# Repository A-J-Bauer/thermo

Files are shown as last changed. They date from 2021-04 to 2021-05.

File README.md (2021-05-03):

# thermo
A simple DIY thermometer and PWA app.

This is a little fun project using cheap components to build a thermometer that can be connected to a smart phone's or computer's USB interface.

Installable PWA (Chrome only) here: https://a-j-bauer.github.io/thermo/

For phones you need an OTG USB cable.

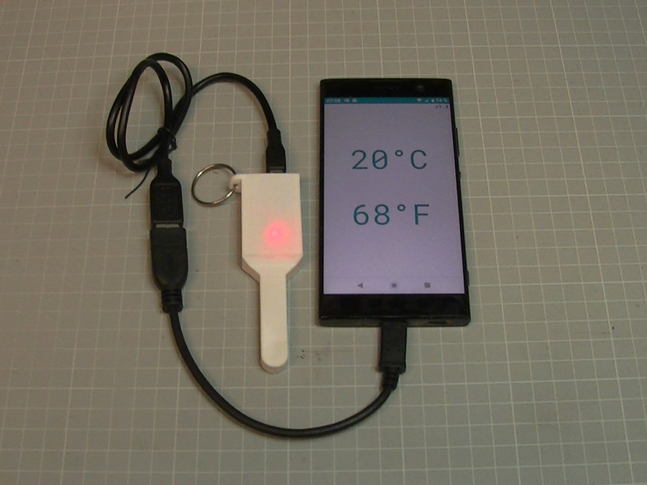
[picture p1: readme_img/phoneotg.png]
phone with otg cable


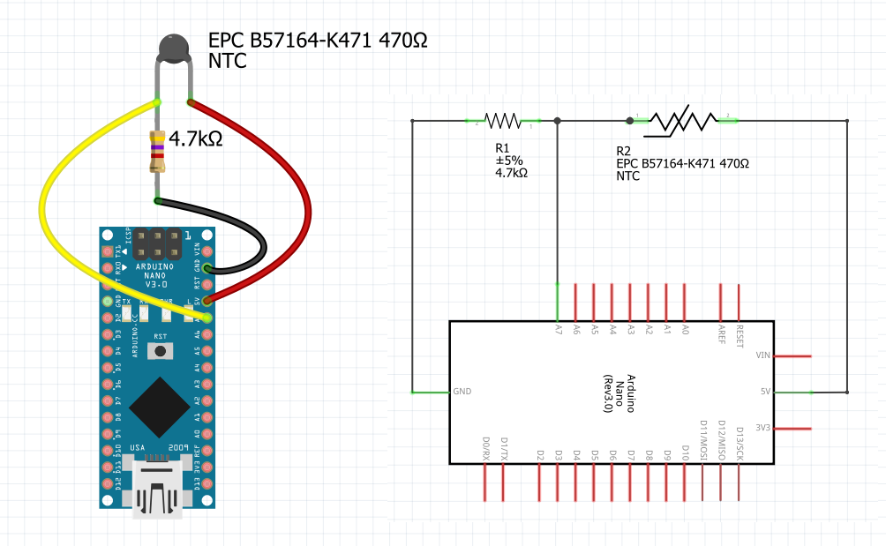
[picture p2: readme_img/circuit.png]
circuit


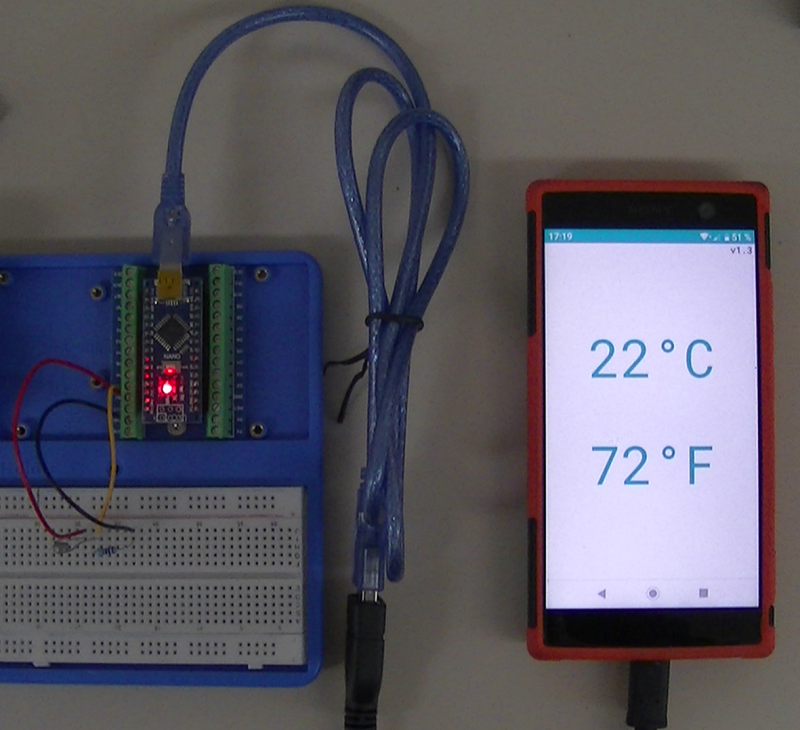
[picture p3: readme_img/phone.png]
phone


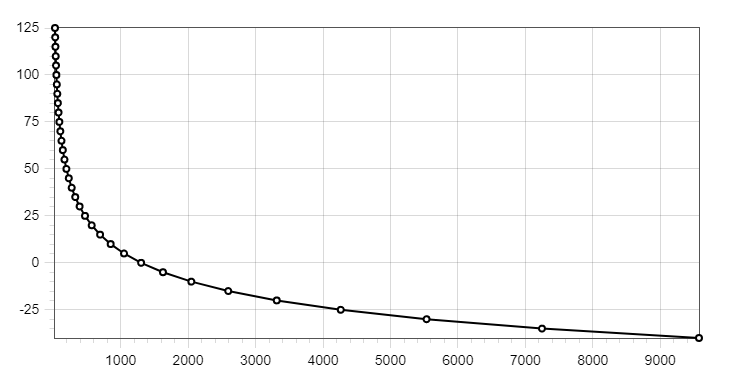
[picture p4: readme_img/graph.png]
graph


**Circuit Notes:**

The circuit is a simple voltage divider where one of the resistors is a negative temperature coefficient (NTC) thermistor, meaning it's resistance will get lower as it's temperature gets higher. At 25°C the resistance of the NTC used here is 470Ω. To avoid self heating the current flowing through the thermistor is limited by the second resistor. I picked 4.7kΩ. Knowing that the resistance is measured in terms of voltage drop accross the NTC at a certain resolution (Nano 10bits, 1024 steps for 5V, 4.9 mV/step) and looking at the data graph leads to the conclusion that the accuracy will degrade as the temperature rises.
More info: [Wikipedia Thermistor](https://en.wikipedia.org/wiki/Thermistor)

**Sensor Placement**

The Arduino itself creates heat so the NTCs position and wire length should be chosen accoringly.

The first design picked up the heat from the Microcontroller:

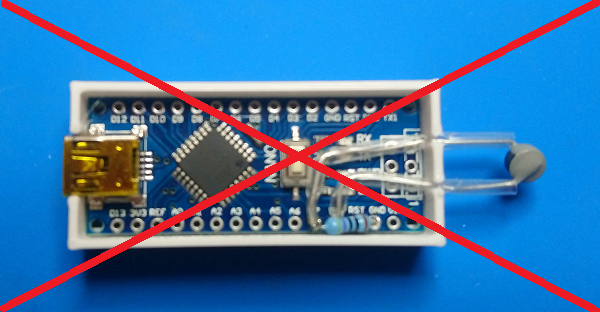
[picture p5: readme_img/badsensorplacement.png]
bad sensor placement


The second design decouples from the Arduino's heat much better:

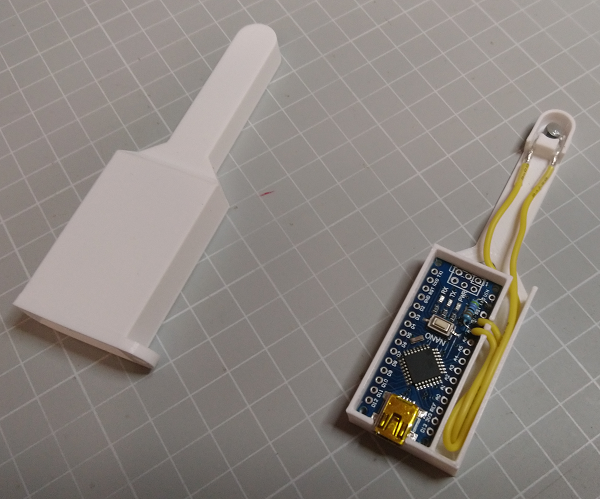
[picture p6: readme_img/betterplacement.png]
better placement


Note: The pocket where the NTC is seated in is filled up with glue a little over the brim now so that the heat from outside transfers to the NTC a little bit better/faster.

**Source Note:**
The serial.js is a modified version of Google's Serial Polyfill from here https://github.com/google/web-serial-polyfill.
The modified version helps to get the PWA to also works with Arduino clones on Android phones (Apple not tested).

**Arduino sketch Notes:**

The sketch measures the resistance of the NTC with 10bit resolution and then searches in the resistance values pulled from the NTC's datasheet to find the two values it falls in between.
The indices of these values correspond to the values of the temperature array. From there a simple linear approximation is used to calculate the final temperature which then is rounded and sent to the serial ouput.

```
#define R25 470.0f
#define RKNOWN 4700.0f
#define RWIRE 0.2f
#define ARRAY_SIZE 34

// from datasheet
float Array_RT[] = {9573.90f, 7245.52f, 5534.25f, 4262.81f, 3313.36f, 2593.79f, 2047.23f, 1626.62f, 1302.14f, 1048.71f, 850.61f, 693.81f, 569.45f, 470.00f, 390.02f, 325.33f, 272.80f, 229.83f, 194.56f, 165.43f, 141.28f, 121.17f, 104.33f, 90.19f, 78.25f, 68.14f, 59.54f, 52.21f, 45.93f, 40.53f, 35.87f, 31.85f, 28.35f, 25.31f};
float Array_T[] = {-40.0f, -35.0f, -30.0f, -25.0f, -20.0f, -15.0f, -10.0f, -5.0f, 0.0f, 5.0f, 10.0f, 15.0f, 20.0f, 25.0f, 30.0f, 35.0f, 40.0f, 45.0f, 50.0f, 55.0f, 60.0f, 65.0f, 70.0f, 75.0f, 80.0f, 85.0f, 90.0f, 95.0f, 100.0f, 105.0f, 110.0f, 115.0f, 120.0f, 125.0f};

int a7;

float RT;
float T = -273.15;

int idx1, idx2;

void setup() {
  Serial.begin(19200);
  
  pinMode(LED_BUILTIN, OUTPUT);
  
  // blink fast to indicate startup / reset
  for (int i=0; i<5; i++){
    digitalWrite(LED_BUILTIN, HIGH);
    delay(50);
    digitalWrite(LED_BUILTIN, LOW);
    delay(50);
  }  
}

void loop() {
  digitalWrite(LED_BUILTIN, HIGH);
  delay(1000);

  a7 = analogRead(7); // 10 bit => a7 ε [0..1023]

  // example 2 bit  : a7 € [0..3]    => 0 == 0 * 5/3 V,    1 == 1 * 5/3V , 2 == 2 * 5/3 V, 3 == 3 * 5/3 V
  // example 10 bit : a7 € [0..1023] => 0 == 0 * 5/1023 V, 1 == 1 * 5/1023 V, ..., 1023 == 1023 * 5/1023 V
  
  // https://en.wikipedia.org/wiki/Voltage_divider (Resistive divider)
  // a7 = 1023 * RKNOWN / (RT + RKNOWN)
  // => (RT + RKNOWN) = 1023 * RKNOWN / a7
  // => RT = 1023 * RKNOWN / a7 - RKNOWN
  // => RT = RKNOWN * (1023 / a7 - 1)
  
  RT = RKNOWN * (1023.0f / (float)a7 - 1.0f) + RWIRE;
    
  for (int i=1; i < ARRAY_SIZE; i++) {
    if (Array_RT[i] < RT){
      idx1 = i - 1;
      idx2 = i;  
      break;          
    }
  }
    
  T = (Array_T[idx2] - Array_T[idx1]) / (Array_RT[idx2] - Array_RT[idx1]) * (RT - Array_RT[idx1]) + Array_T[idx1];    

  /*Serial.print("a7: "); Serial.print(a7); Serial.print(" ");
  Serial.print("RT: "); Serial.print(RT); Serial.print(" ");
  Serial.print("idx1: "); Serial.print(idx1); Serial.print(" ");
  Serial.print("idx2: "); Serial.print(idx2); Serial.print(" ");
  Serial.print("Array_RT[idx1]: "); Serial.print(Array_RT[idx1]); Serial.print(" ");
  Serial.print("Array_RT[idx2]: "); Serial.print(Array_RT[idx2]); Serial.print(" ");
  Serial.print("Array_T[idx1]: "); Serial.print(Array_T[idx1]); Serial.print(" ");
  Serial.print("Array_T[idx2]: "); Serial.print(Array_T[idx2]); Serial.print(" ");
  Serial.print("T: "); Serial.print(T); Serial.print(" ");
  Serial.print("round(T): "); Serial.print(round(T)); Serial.print(" ");*/
  Serial.println(round(T));

  digitalWrite(LED_BUILTIN, LOW);
  delay(1000);

}
```

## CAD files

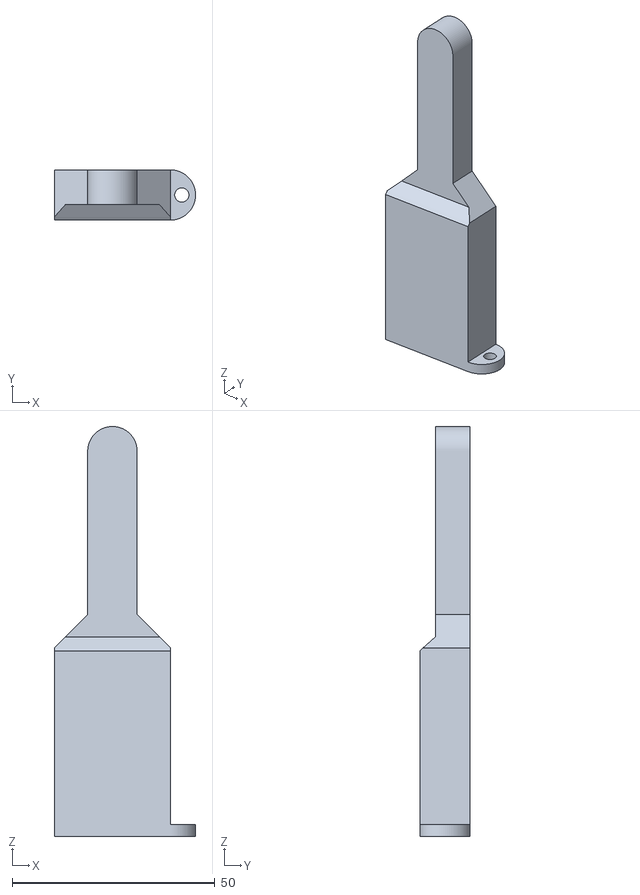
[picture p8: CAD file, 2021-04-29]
stl/thermoshell.stl
34.8 x 12.4 x 101.1

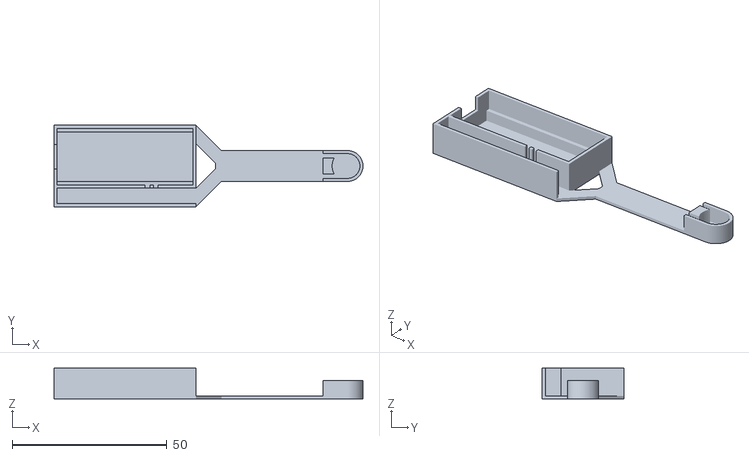
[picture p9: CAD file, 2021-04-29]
stl/thermobody.stl
100.0 x 26.4 x 10.0
